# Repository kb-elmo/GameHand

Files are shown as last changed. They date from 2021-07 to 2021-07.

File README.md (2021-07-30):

# GameHand

[][cc-by-nc-sa] 
<a href="https://ko-fi.com/kb_elmo">kofibadge</a>

### Left-hand gaming keypad with a 3D printed case



---

[Case files](case/)

[KiCAD PCB files](pcb/)

[Gerbers for PCB production](pcb/gerbers/)

[JLCPCB BOM](pcb/fab/GameHand_bom_jlc.csv)

[JLCPCB CPL](pcb/fab/GameHand_cpl_jlc.csv)

---

This work is licensed under a
[Creative Commons Attribution-NonCommercial-ShareAlike 4.0 International License][cc-by-nc-sa].

[][cc-by-nc-sa]

[cc-by-nc-sa]: http://creativecommons.org/licenses/by-nc-sa/4.0/
[cc-by-nc-sa-image]: https://licensebuttons.net/l/by-nc-sa/4.0/88x31.png
[cc-by-nc-sa-shield]: https://img.shields.io/badge/License-CC%20BY--NC--SA%204.0-lightgrey.svg

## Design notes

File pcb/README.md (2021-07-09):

# GameHand PCB

---

The GameHand PCB is powered by an ATmega32u2 MCU and has basic ESD and overvoltage protection.  

With the firmware files in this repo the board is capable of full NKRO and 1000 Hz USB polling.

---

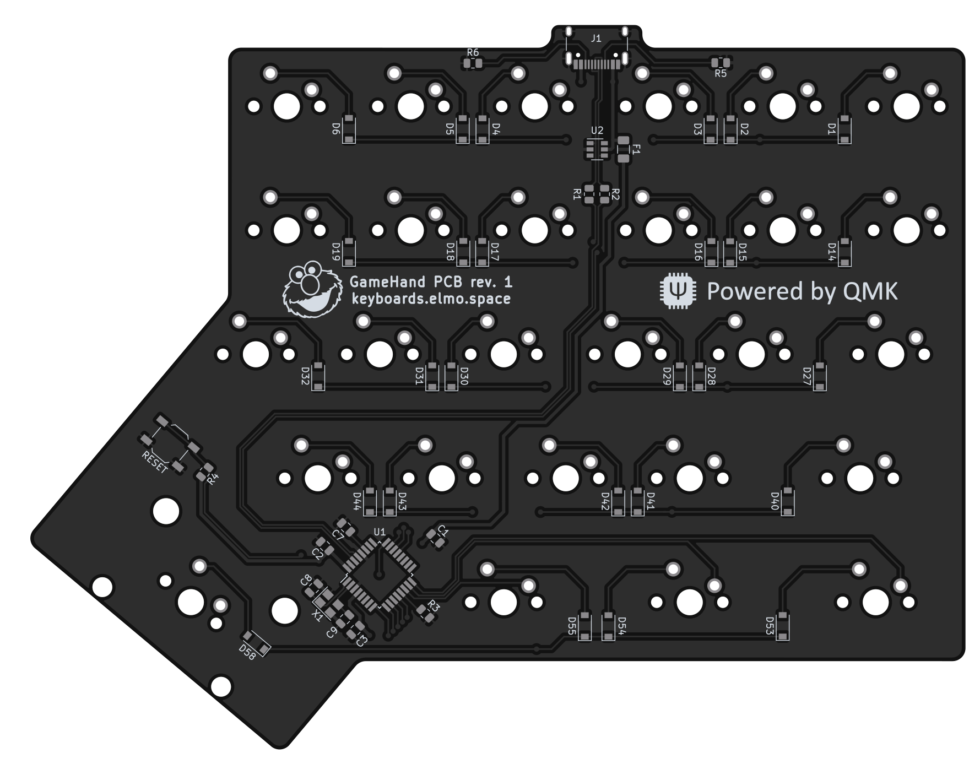
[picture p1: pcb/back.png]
pcb_back
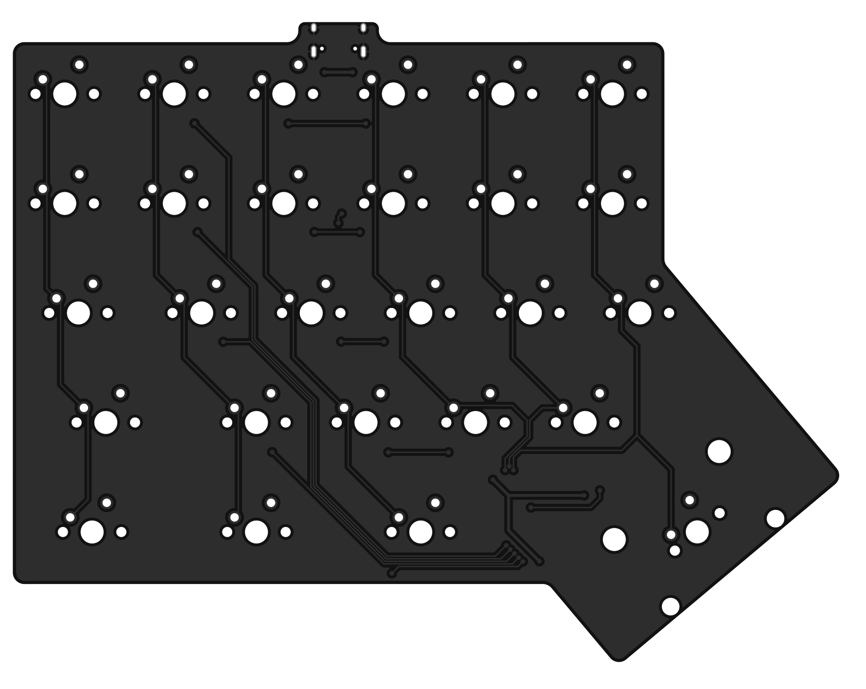
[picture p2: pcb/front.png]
pcb_front


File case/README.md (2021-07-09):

# GameHand case

### These files are meant for 3D printing only! 

They are not suitable for CNC machining at all and trying to do so will result in failure of the part.

5x M2 screws are required for assembly.

The wrist rest pad can be made out of simple 5mm thick EPDM foam (can be found in any decent hardware store).  

[Cutting template for the pad](pad_outline.dxf)

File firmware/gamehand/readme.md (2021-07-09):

# GameHand

gamehand

A left-hand gaming keypad with a 3D printed case

* Keyboard Maintainer: [kb-elmo](https://github.com/kb-elmo)
* Hardware Supported: GameHand rev.1 PCB
* Hardware Availability: [OpenSource Project](https://github.com/kb-elmo/GameHand)

Make example for this keyboard (after setting up your build environment):

    make gamehand:default

Flashing example for this keyboard:

    make gamehand:default:flash

**Bootloader:** Press the physical reset button on the bottom side of the PCB (labeled Reset) or hold down the top left key while plugging in the board.

See the [build environment setup](https://docs.qmk.fm/#/getting_started_build_tools) and the [make instructions](https://docs.qmk.fm/#/getting_started_make_guide) for more information. Brand new to QMK? Start with our [Complete Newbs Guide](https://docs.qmk.fm/#/newbs).

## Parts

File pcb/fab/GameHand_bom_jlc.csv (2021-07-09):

Comment | Designator | Footprint | LCSC Part #
10uF | C1 | C_0805_2012Metric | C91245
0.1uF | C2,C3 | C_0805_2012Metric | C49678
1uF | C7 | C_0805_2012Metric | C28323
22pF | C8,C9 | C_0805_2012Metric | C1804
D_Small | D1,D2,D3,D4,D5,D6,D14,D15,D16,D17,D18,D19,D27,D28,D29,D30,D31,D32,D40,D41,D42,D43,D44,D53,D54,D58,D55 | D_SOD-123 | C81598
Polyfuse_Small | F1 | Fuse_1206_3216Metric | C69688
22r | R1,R2 | R_0805_2012Metric | C17561
10k | R3,R4 | R_0805_2012Metric | C17414
5.1k | R5,R6 | R_0805_2012Metric | C27834
SW_Push | RESET | SW_SPST_TL3342 | C318884
SRV05-4 | U2 | SOT-23-6 | C85364
Crystal_GND24_Small | X1 | Crystal_SMD_3225-4Pin_3.2x2.5mm | C13738

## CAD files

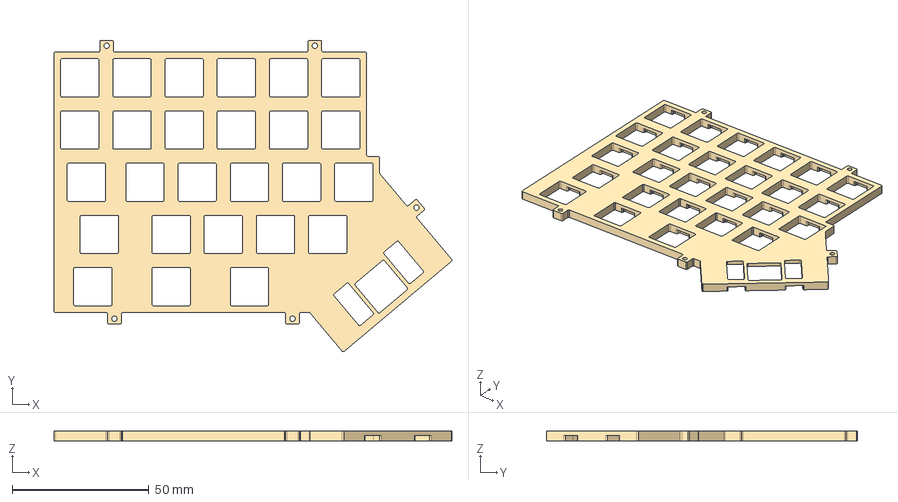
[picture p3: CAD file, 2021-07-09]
case/plate.step
145.3 x 113.7 x 3.50 mm

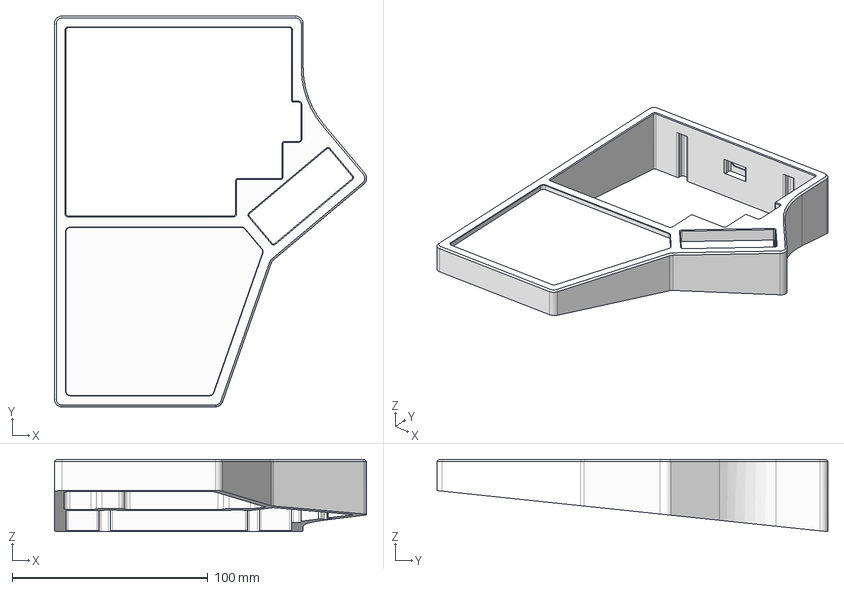
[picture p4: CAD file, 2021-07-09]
case/case.step
159.7 x 200.0 x 37.0 mm

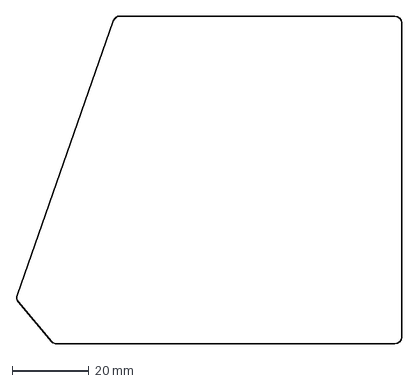
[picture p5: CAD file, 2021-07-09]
case/pad_outline.dxf
100.3 x 85.4 mm

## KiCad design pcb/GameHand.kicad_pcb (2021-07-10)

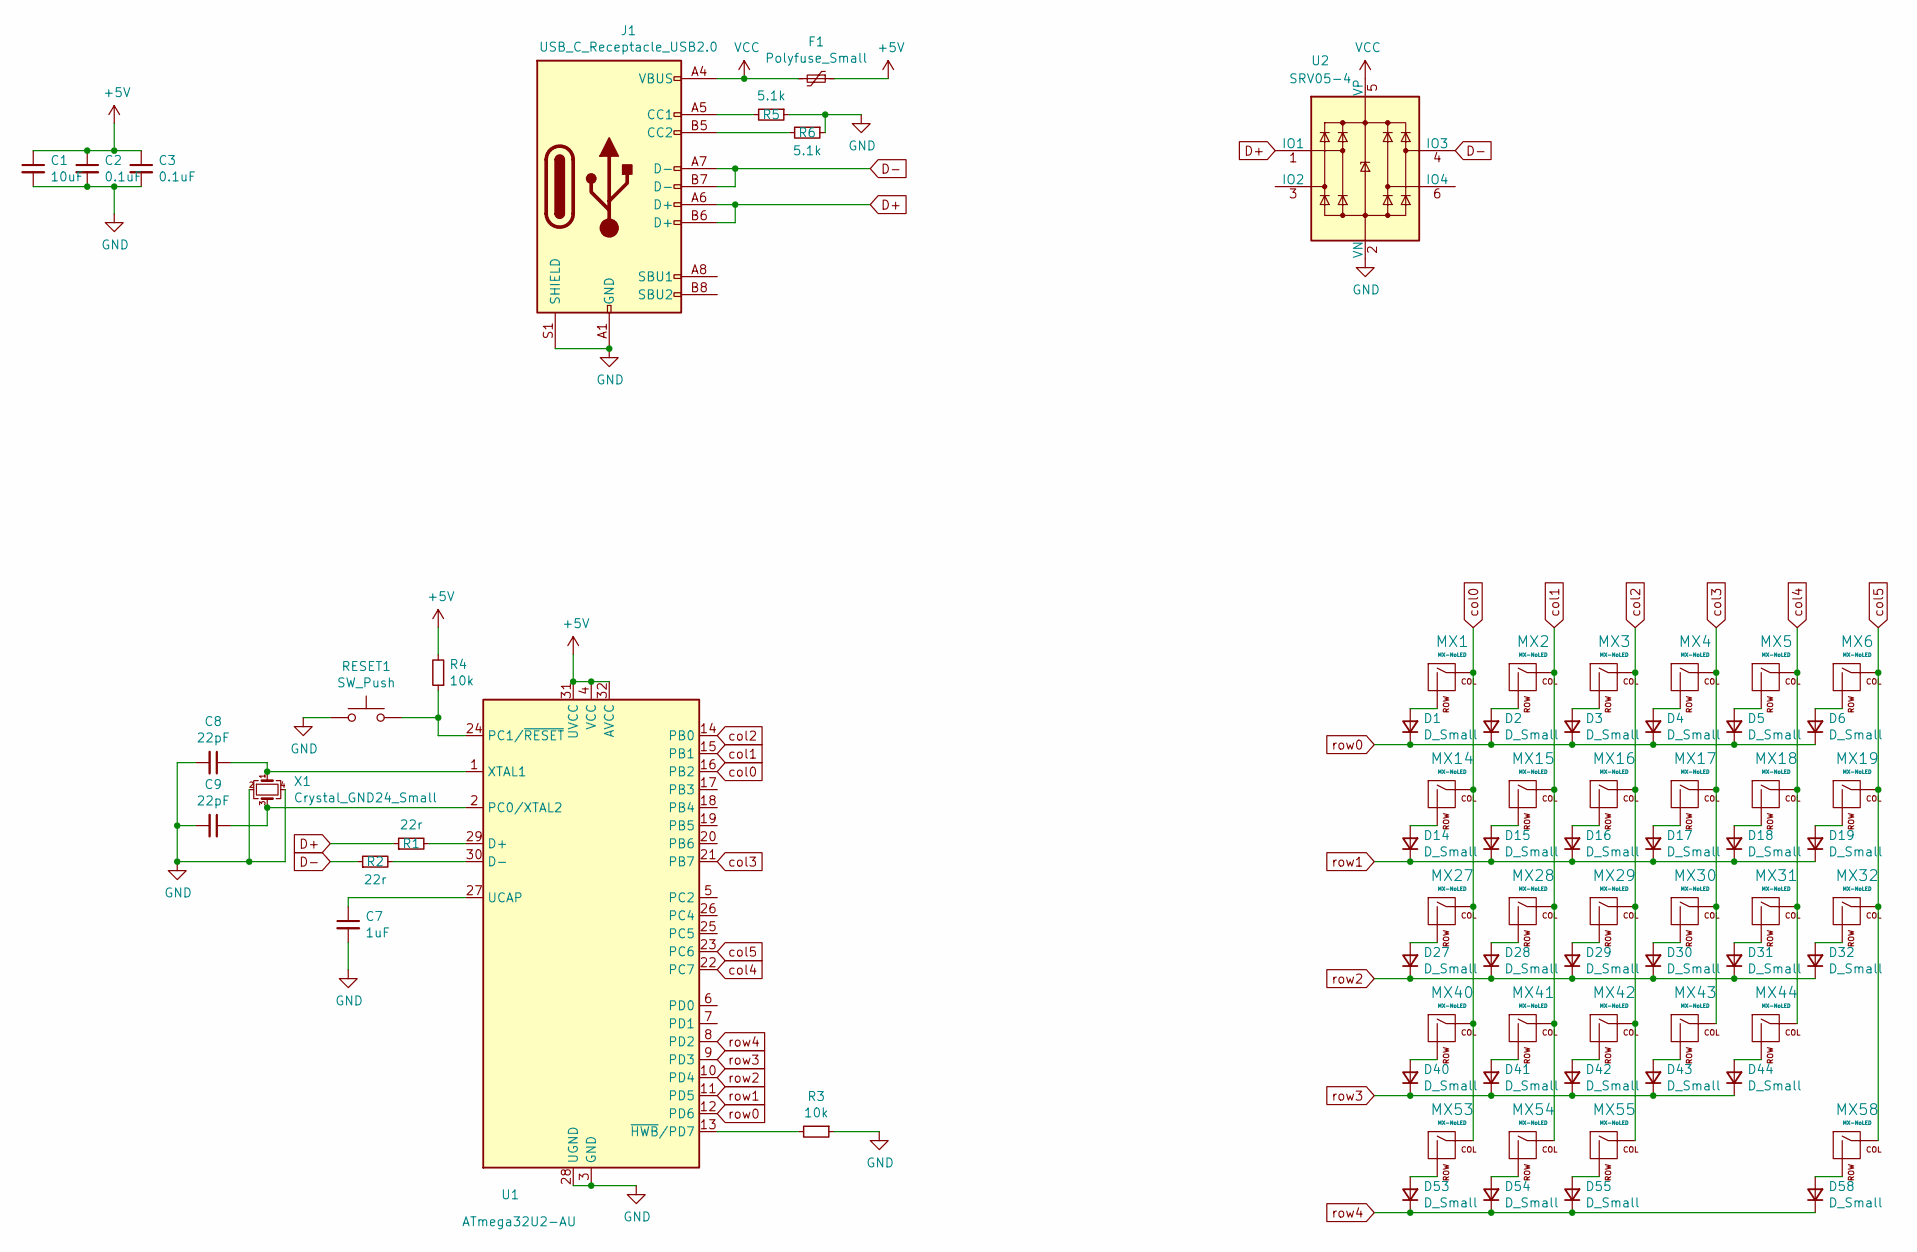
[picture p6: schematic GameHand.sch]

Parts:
C1: 10uF; C_0805_2012Metric; LCSC C91245
C2, C3: 0.1uF; C_0805_2012Metric; LCSC C49678
C7: 1uF; C_0805_2012Metric; LCSC C28323
C8, C9: 22pF; C_0805_2012Metric; LCSC C1804
D1, D2, D3, D4, D5, D6, D14, D15, D16, D17, D18, D19, D27, D28, D29, D30, D31, D32, D40, D41, D42, D43, D44, D53, D54, D55, D58: D_Small; D_SOD-123; LCSC C81598
F1: Polyfuse_Small; Fuse_1206_3216Metric; LCSC C69688
J1: USB_C_Receptacle_USB2.0; USB_C_Receptacle_HRO_TYPE-C-31-M-12
MX1, MX2, MX3, MX4, MX5, MX6, MX14, MX15, MX16, MX17, MX18, MX19, MX28, MX29, MX30, MX31, MX32, MX41, MX42, MX43, MX44: MX-NoLED; MXOnly-1U-NoLED
MX27: MX-NoLED; MXOnly-1.25U-NoLED
MX40: MX-NoLED; MXOnly-1.75U-NoLED
MX53, MX54, MX55: MX-NoLED; MXOnly-1.5U-NoLED
MX58: MX-NoLED; MXOnly-2.75U-ReversedStabilizers-NoLED
R1, R2: 22r; R_0805_2012Metric; LCSC C17561
R3, R4: 10k; R_0805_2012Metric; LCSC C17414
R5, R6: 5.1k; R_0805_2012Metric; LCSC C27834
RESET1: SW_Push; SW_SPST_TL3342; LCSC C318884
U1: ATmega32U2-AU; TQFP-32_7x7mm_P0.8mm
U2: SRV05-4; SOT-23-6; LCSC C85364
X1: Crystal_GND24_Small; Crystal_SMD_3225-4Pin_3.2x2.5mm; LCSC C13738

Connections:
+5V: C1.1, C2.1, C3.1, F1.1, R4.2, U1.4 (VCC), U1.31 (UVCC), U1.32 (AVCC)
D+: J1.A6 (D+), J1.B6 (D+), R1.1, U2.1 (IO1)
D-: J1.A7 (D-), J1.B7 (D-), R2.1, U2.4 (IO3)
GND: C1.2, C2.2, C3.2, C7.2, C8.2, C9.2, J1.A1 (GND), J1.A12 (GND), J1.B1 (GND), J1.B12 (GND), J1.S1 (SHIELD), R3.1, R5.1, R6.1, RESET1.1, U1.3 (GND), U1.28 (UGND), U2.2 (VN), X1.2, X1.4; also elsewhere on the board
unnamed: C7.1, U1.27 (UCAP)
unnamed: C8.1, U1.1 (XTAL1), X1.1
unnamed: C9.1, U1.2 (PC0/XTAL2), X1.3
unnamed: D1.2 (A), MX1.2 (ROW)
unnamed: D2.2 (A), MX2.2 (ROW)
unnamed: D3.2 (A), MX3.2 (ROW)
unnamed: D4.2 (A), MX4.2 (ROW)
unnamed: D5.2 (A), MX5.2 (ROW)
unnamed: D6.2 (A), MX6.2 (ROW)
unnamed: D14.2 (A), MX14.2 (ROW)
unnamed: D15.2 (A), MX15.2 (ROW)
unnamed: D16.2 (A), MX16.2 (ROW)
unnamed: D17.2 (A), MX17.2 (ROW)
unnamed: D18.2 (A), MX18.2 (ROW)
unnamed: D19.2 (A), MX19.2 (ROW)
unnamed: D27.2 (A), MX27.2 (ROW)
unnamed: D28.2 (A), MX28.2 (ROW)
unnamed: D29.2 (A), MX29.2 (ROW)
unnamed: D30.2 (A), MX30.2 (ROW)
unnamed: D31.2 (A), MX31.2 (ROW)
unnamed: D32.2 (A), MX32.2 (ROW)
unnamed: D40.2 (A), MX40.2 (ROW)
unnamed: D41.2 (A), MX41.2 (ROW)
unnamed: D42.2 (A), MX42.2 (ROW)
unnamed: D43.2 (A), MX43.2 (ROW)
unnamed: D44.2 (A), MX44.2 (ROW)
unnamed: D53.2 (A), MX53.2 (ROW)
unnamed: D54.2 (A), MX54.2 (ROW)
unnamed: D55.2 (A), MX55.2 (ROW)
unnamed: D58.2 (A), MX58.2 (ROW)
unnamed: J1.A5 (CC1), R5.2
unnamed: J1.B5 (CC2), R6.2
unnamed: R1.2, U1.29 (D+)
unnamed: R2.2, U1.30 (D-)
unnamed: R3.2, U1.13 (~HWB~/PD7)
unnamed 41: R4.1, RESET1.2, U1.24 (PC1/~RESET); also elsewhere on the board
VCC: F1.2, J1.A4 (VBUS), J1.A9 (VBUS), J1.B4 (VBUS), J1.B9 (VBUS), U2.5 (VP)
col0: MX1.1 (COL), MX14.1 (COL), MX27.1 (COL), MX40.1 (COL), MX53.1 (COL), U1.16 (PB2)
col1: MX2.1 (COL), MX15.1 (COL), MX28.1 (COL), MX41.1 (COL), MX54.1 (COL), U1.15 (PB1)
col2: MX3.1 (COL), MX16.1 (COL), MX29.1 (COL), MX42.1 (COL), MX55.1 (COL), U1.14 (PB0)
col3: MX4.1 (COL), MX17.1 (COL), MX30.1 (COL), MX43.1 (COL), U1.21 (PB7)
col4: MX5.1 (COL), MX18.1 (COL), MX31.1 (COL), MX44.1 (COL), U1.22 (PC7)
col5: MX6.1 (COL), MX19.1 (COL), MX32.1 (COL), MX58.1 (COL), U1.23 (PC6)
row0: D1.1 (K), D2.1 (K), D3.1 (K), D4.1 (K), D5.1 (K), D6.1 (K), U1.12 (PD6)
row1: D14.1 (K), D15.1 (K), D16.1 (K), D17.1 (K), D18.1 (K), D19.1 (K), U1.11 (PD5)
row2: D27.1 (K), D28.1 (K), D29.1 (K), D30.1 (K), D31.1 (K), D32.1 (K), U1.10 (PD4)
row3: D40.1 (K), D41.1 (K), D42.1 (K), D43.1 (K), D44.1 (K), U1.9 (PD3)
row4: D53.1 (K), D54.1 (K), D55.1 (K), D58.1 (K), U1.8 (PD2)

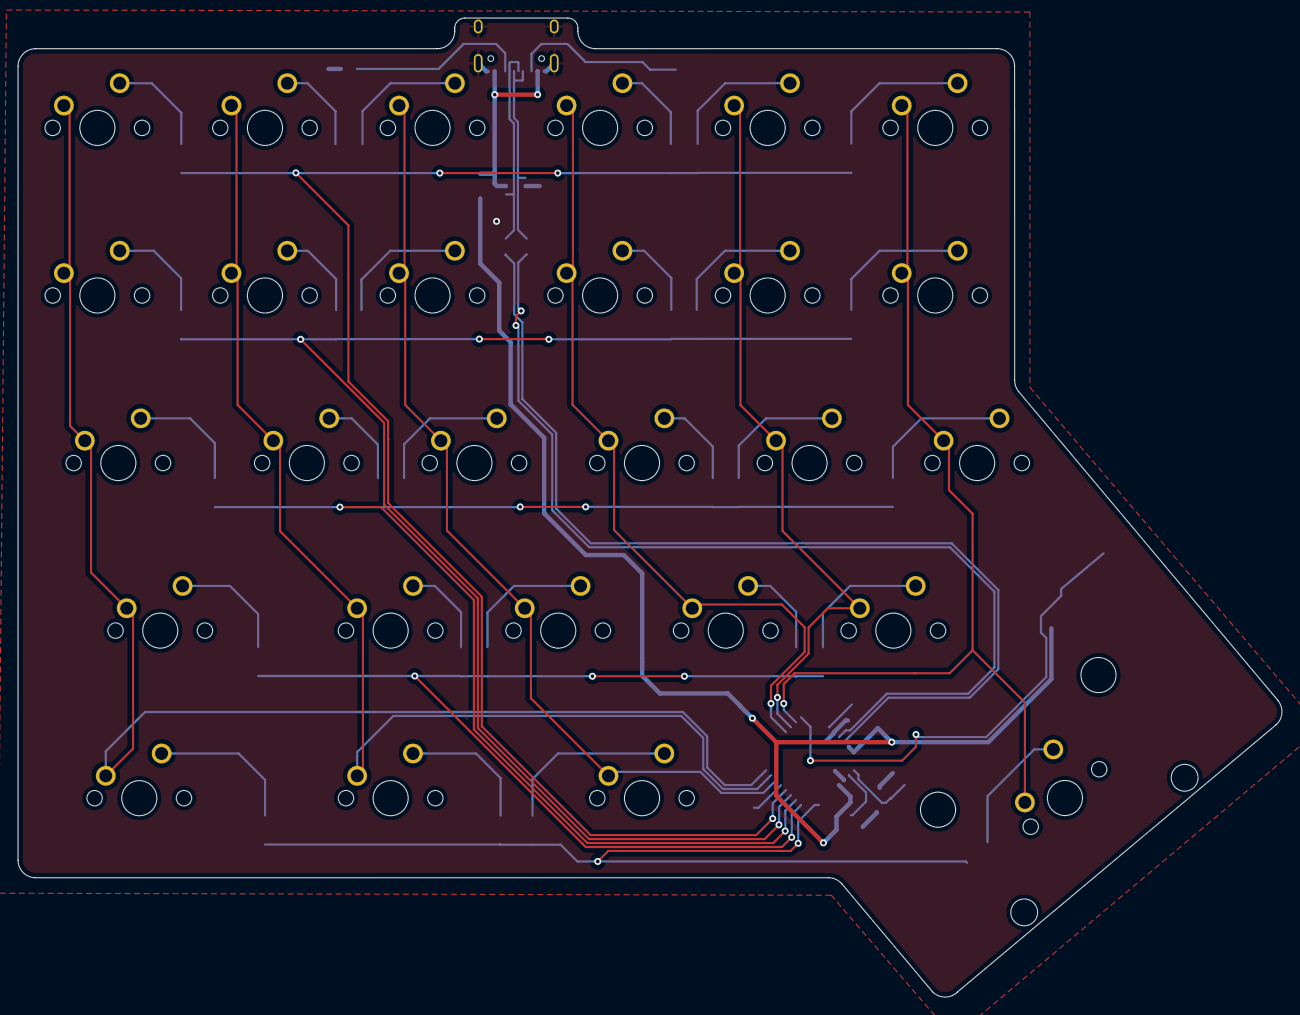
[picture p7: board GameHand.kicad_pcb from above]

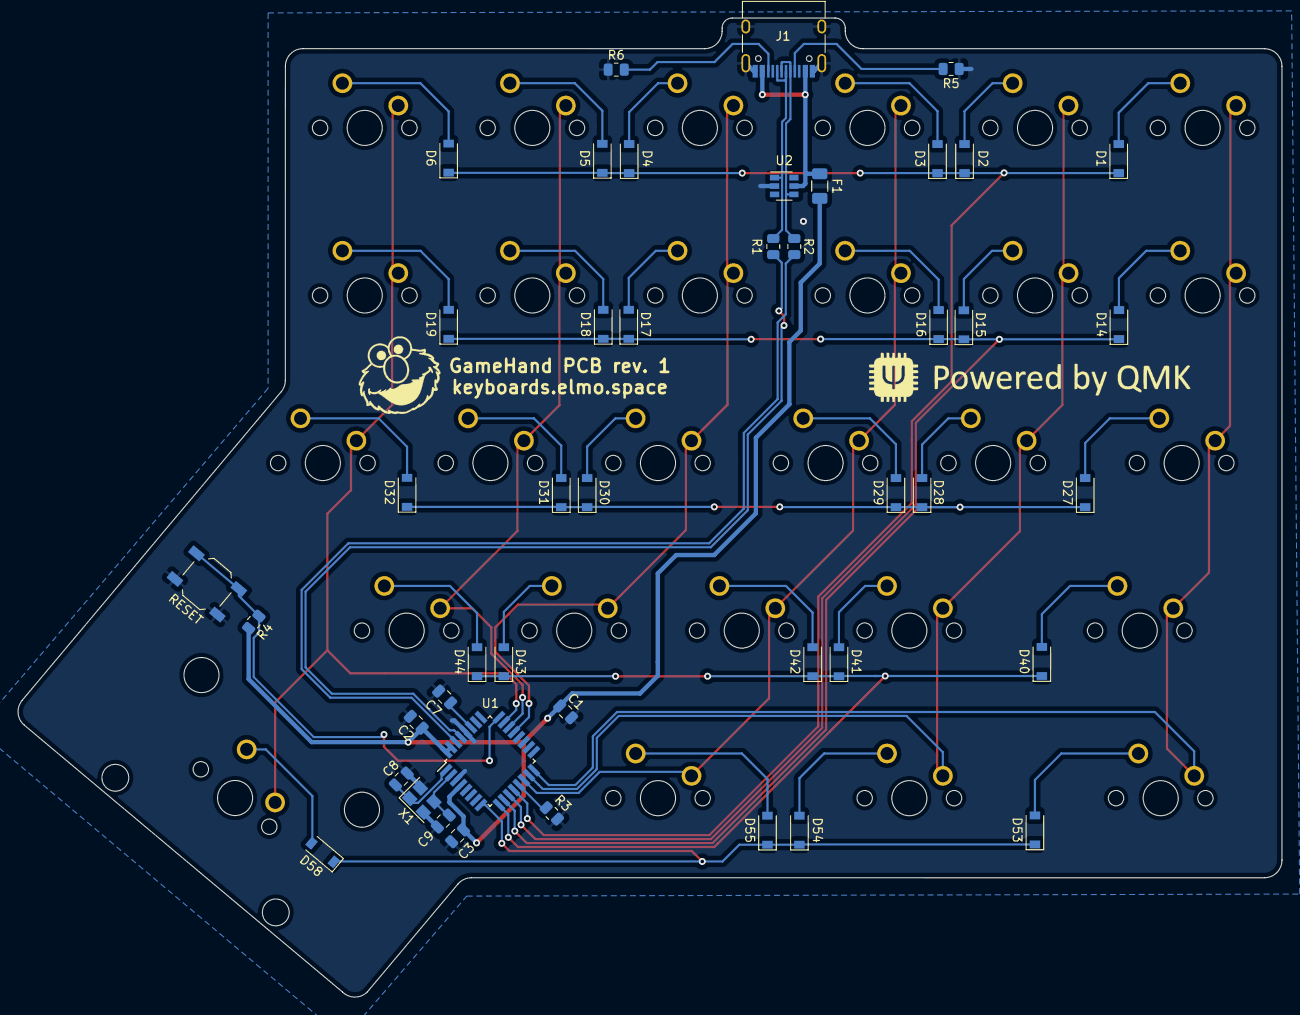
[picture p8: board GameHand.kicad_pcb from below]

Board: 2 copper layers, 143.7 x 111.3 mm, 72 parts (45 on the bottom side), 52 nets.

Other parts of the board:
RESET: SW_Push; SW_SPST_TL3342

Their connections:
GND: RESET.1; also elsewhere on the board
unnamed 41: RESET.2; also elsewhere on the board

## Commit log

2021-07-09 add PCB files
    [GameHand-B_Cu.gbr, GameHand-B_Mask.gbr, GameHand-B_Paste.gbr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]
2021-07-10 update gerbers
    [GameHand-B_Cu.gbr, GameHand-B_Mask.gbr, GameHand-B_Paste.gbr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]
2021-07-10 remove unused corner cutouts
    [GameHand-B_Cu.gbr, GameHand-B_Mask.gbr, GameHand-B_Paste.gbr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]
2021-07-10 update drillfiles
    [GameHand-NPTH.drl, GameHand-PTH.drl]

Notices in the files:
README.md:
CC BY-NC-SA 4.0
